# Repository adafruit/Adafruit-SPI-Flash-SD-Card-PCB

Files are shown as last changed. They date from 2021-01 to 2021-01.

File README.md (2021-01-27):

## Adafruit SPI Flash SD Card PCB

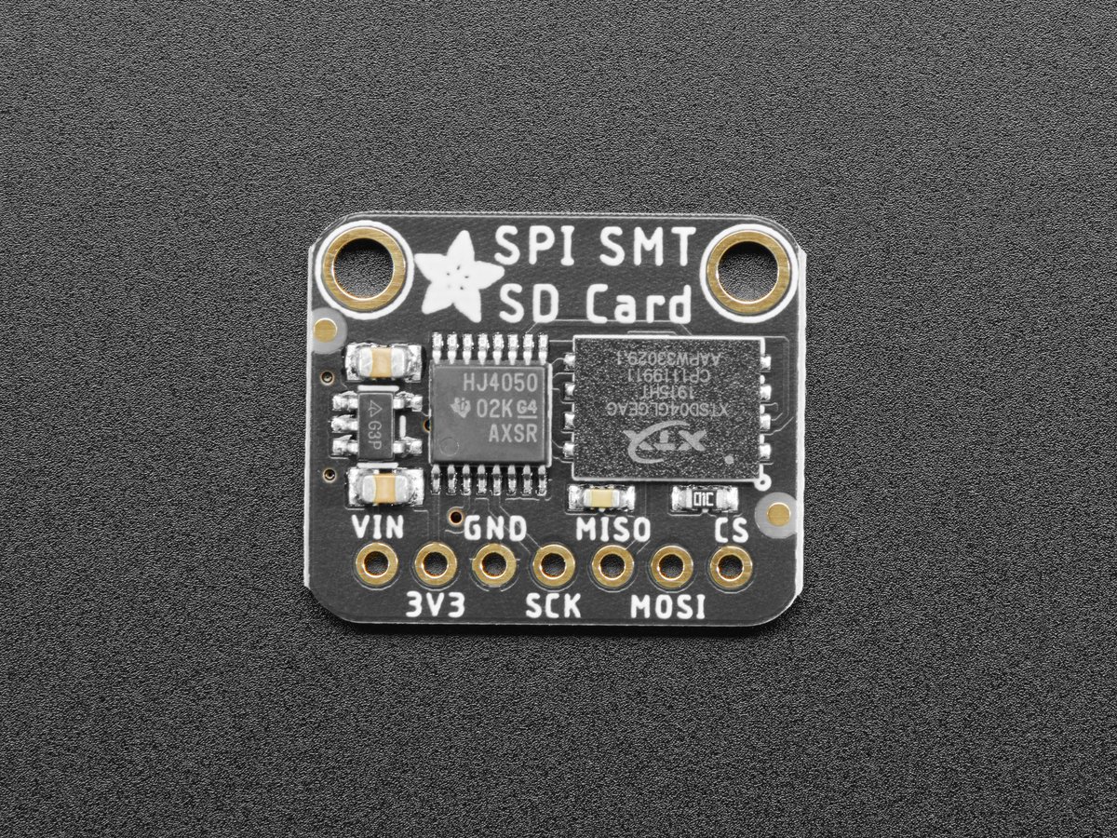
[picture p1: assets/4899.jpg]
<a href="http://www.adafruit.com/products/4899"><br/>
Click here to purchase one from the Adafruit shop</a>

PCB files for the Adafruit SPI Flash SD Card.

Format is EagleCAD schematic and board layout
* https://www.adafruit.com/product/4899

### Description

This breakout is for a fascinating chip - it looks like an SPI Flash storage chip (like the GD25Q16) but its really an SD card, in an SMT chip format. What that means is that you wire up like an SD card breakout, and use the SD card libraries you already have for your microcontroller. For example, you can use the built in SD library in Arduino, or for CircuitPython we have an sdcard library. The breakout will act just like a 512 MB sized card with FAT formatting (it's pre-formatted).

You might be wondering why you'd want such a thing - after all you can't plug it into a computer to get the files off like MicroSD cards. For some use cases, such as data logging in a high-vibration device where you don't want the SD card to come loose, or for when you need to reduce size, or when the microcontroller provides a USB mass storage interface, this chip could very useful.

Compared to plain SPI flash, this NAND memory chip handles all the wear leveling and ECC calculation. You don't have to manually erase blocks, you just write and read them like you would with any SD card.You can clock it up 50 MHz and the 'write speed class' is 8 (although you may not be able to get that fast with plain 1-bit SPI compared to SDIO).

We made this breakout to be a quickstart for this chip. We wired the chip in "SPI" mode, with a level shifters so you can use it with 3V or 5V logic easily. You also get a 3.3V regulator and a pullup on CS. Wire up the SPI pins to your microcontroller, use your favorite SD library and you'll be ready to rock in minutes!

### License

Adafruit invests time and resources providing this open source design, please support Adafruit and open-source hardware by purchasing products from [Adafruit](https://www.adafruit.com)!

Designed by Limor Fried/Ladyada for Adafruit Industries.

Creative Commons Attribution/Share-Alike, all text above must be included in any redistribution.
See license.txt for additional details.

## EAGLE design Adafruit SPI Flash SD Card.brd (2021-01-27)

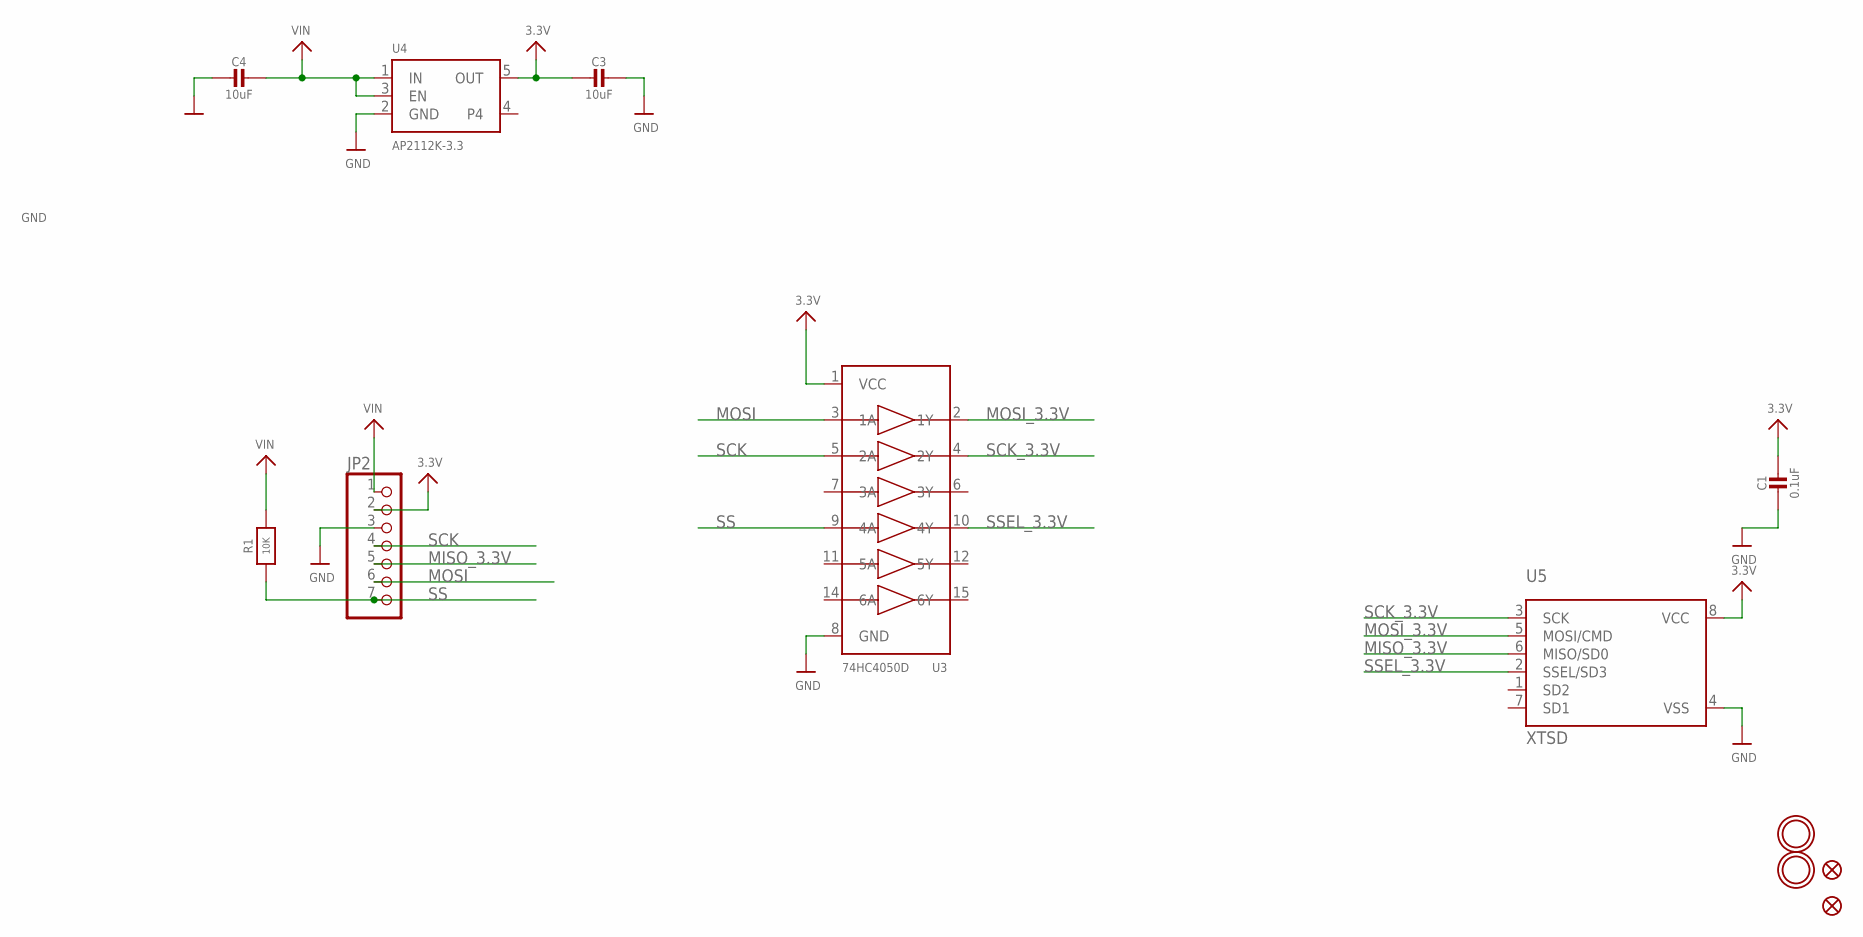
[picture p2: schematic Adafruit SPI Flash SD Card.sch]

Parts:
C1: 0.1uF; 0603-NO
C3, C4: 10uF; 0805-NO
FID2, FID3: FIDUCIAL_1MM
JP2: HEADER-1X770MIL; 1X07_ROUND_70
R1: 10K; 0603-NO
U3: 74HC4050D; TSSOP16
U4: AP2112K-3.3; SOT23-5
U5: XTSD; LGA8_8X6
U$16, U$17: MOUNTINGHOLE2.5; MOUNTINGHOLE_2.5_PLATED

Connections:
3.3V: C1.1, C3.2, JP2.2, U3.1 (VCC), U4.5 (OUT), U5.8 (VCC)
GND: C1.2, C3.1, C4.2, JP2.3, U3.8 (GND), U4.2 (GND), U5.4 (VSS)
MISO_3.3V: JP2.5, U5.6 (MISO/SD0)
MOSI: JP2.6, U3.3 (1A)
MOSI_3.3V: U3.2 (1Y), U5.5 (MOSI/CMD)
SCK: JP2.4, U3.5 (2A)
SCK_3.3V: U3.4 (2Y), U5.3 (SCK)
SS: JP2.7, R1.1, U3.9 (4A)
SSEL_3.3V: U3.10 (4Y), U5.2 (SSEL/SD3)
VIN: C4.1, JP2.1, R1.2, U4.1 (IN), U4.3 (EN)

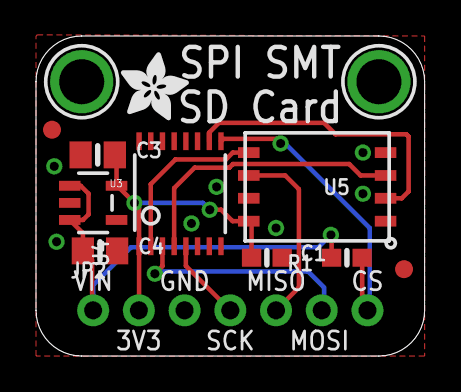
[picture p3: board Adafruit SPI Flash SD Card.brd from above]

Board: 2 copper layers, 21.6 x 17.8 mm, 14 parts (1 on the bottom side), 10 nets.

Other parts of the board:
U$19: ADAFRUIT_3.5MM
U$21: PCBFEAT-REV-040

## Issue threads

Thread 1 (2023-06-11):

MISO output doesn't meet Vih(min) when used with 5V MCU.

doppelhub, 2023-06-11:
This device's 3.3V(nom) MISO output doesn't meet Vih(min) when used with a 5V MCU.  For example, when used with a 328p operating at 5V(nom), the 328p's Vih(min) is VCC*.6.  This means Vih(min) for MISO into the 328p is:
VCC@5.0V: 3V
VCC@5.1V: 3.06V
VCC@5.2V: 3.12V
VCC@5.3V: 3.18V
VCC@5.4V: 3.24V
VCC@5.5V: 3.30V

However, the XTXD08 NAND chip on this card has a specified output Vih(min) of VDD*0.75 and operates at 3.3V(nom).  This 3.3V is sourced onboard from a supply with 1.5% specified uncertainty.  Therefore, when the XTXD08 drives MISO high, the specified Voh(min) is:
VCC@3.25V: 2.44V

Therefore, since this device's specified MISO Voh(min) of 2.44 volts is less than a 5V ATMEGA 328p's Vih(min) of 3.00 volts, there is no guarantee that this device can properly communicate with an Arduino device operating at 5 volts.

doppelhub, 2023-06-11:
One solution to this would be to drive MISO into an open drain NFET channel, with the drain pulled up to VCC.

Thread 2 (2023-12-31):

Does not work with Teensy 4.0

Rocketmanandrew, 2023-12-31:
I have been trying to use this chip with a Teensy 4.0 and it doesn't want to work. For some reason MISO does not go all the way HIGH and CS never goes low. I have tried a lot of things and nothing has worked. Just been trying to run the Cardinfo sketch, always fails to initialize.

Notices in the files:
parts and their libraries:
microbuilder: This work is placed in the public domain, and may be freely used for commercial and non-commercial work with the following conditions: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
